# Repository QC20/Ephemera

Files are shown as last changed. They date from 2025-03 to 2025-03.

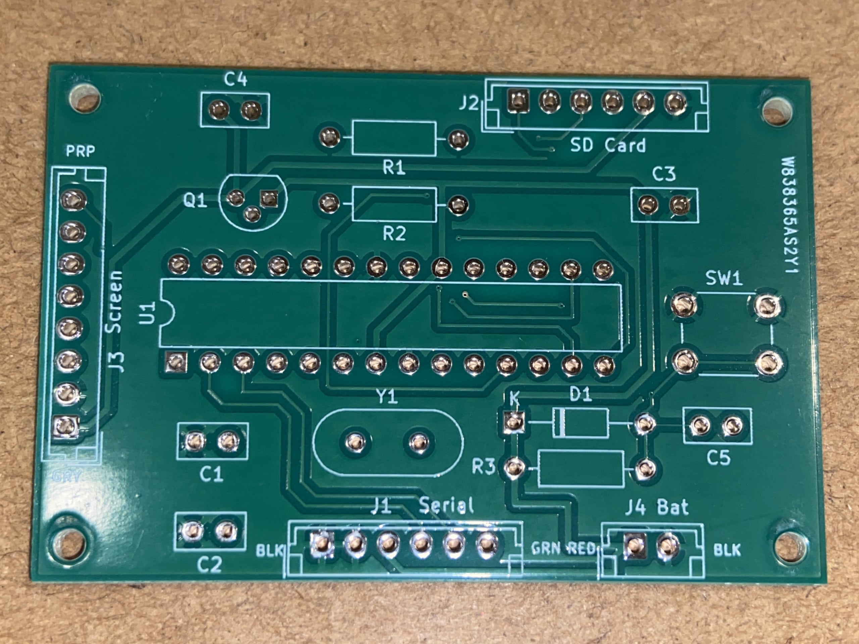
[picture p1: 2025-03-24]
img/pcb-silkscreen-without-components.jpeg

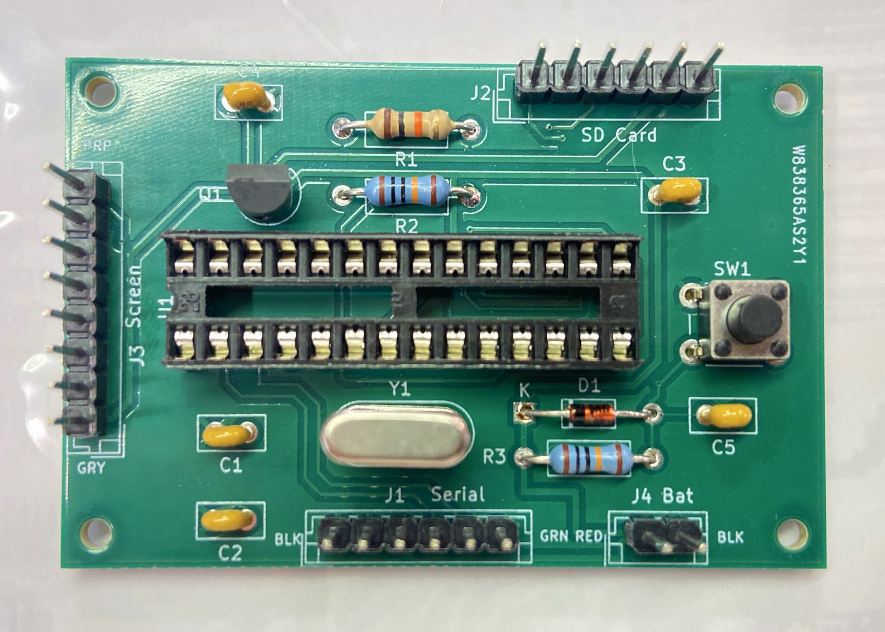
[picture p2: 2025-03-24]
img/pcb-silkscreen-with-components.jpeg

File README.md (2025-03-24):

# Ephemera

This guide offers everything you need to assemble a versatile e-paper picture frame that refreshes its display daily. At its heart is a Waveshare seven-color e-paper display, enhanced with the Floyd-Steinberg Dithering algorithm to give the impression of greater color depth. With the included BMP-Converter, you can easily prepare and customize your own images for display. The frame also supports internet connectivity, allowing you to schedule specific images for special days. Powered by a 1000mAh battery, the setup can run for up to 700 days on a single charge, with convenient recharging available via the ESP32's type-C port.

**Ephemera** is a dynamic e-paper project that brings fresh visual inspiration every day. It curates and displays a new, unique image daily, celebrating the fleeting beauty of each moment. Designed to capture the essence of *ephemera*—the transitory and temporary—this project offers a constantly evolving collection of images, here today and replaced tomorrow.

Whether you're here for daily inspiration, a unique view, or just curious to see what’s new, Ephemera invites you to enjoy each passing frame.

## Features
- **Daily Image Updates:** New content every day to keep things fresh.
- **Minimalist Design:** Clean, distraction-free visuals to let each image stand out.
- **Easy to Extend:** Perfect for those interested in learning about e-paper projects and automation.

---

### The Display 

The Waveshare 7.3" ACeP 7-Color display supports 7 colors (black, white, red, green, blue, orange and yellow).

### Frame Dimensions

The following dimensions are designed to fit the display, so the frame can be any size as long as it accommodates these internal measurements. However, it’s important to ensure there is enough space on the backside for the components. Depending on the battery type you use, the most protruding components will be the crystal and the wires on the PCB, which extend about 10mm. If you can find a  deep frame that allows for this additional space, it would be the ideal solution.

**Dimensions (inches):**  in 5 (L) x 7 in (W)
**Dimensions (mm):** 192 mm (L) x 222 mm (W)

### Components Used in this Project
To bring **Ephemera** to life, you'll need a carefully chosen set of components to ensure low power consumption and seamless operation. Below is a detailed list of the required parts, along with their approximate costs in DKK, to help you build your own dynamic e-paper display.

- **FireBeetle 2 ESP32-E (61.10 DKK):**  
  A microcontroller designed for low power consumption during deep sleep.  
  [Buy here](https://www.dfrobot.com/product-2195.html)

- **Li-Po 503450 1000mAh 3.7V with PH2.0 connector (~17.20 DKK each):**  
  A rechargeable lithium polymer battery for power supply.  
  *(Dimensions: 5mm (H) x 34mm (W) x 50mm (L))*  
  [Buy here](https://yourlink.com)

- **Micro SD Card Module (~2.80 DKK each):**  
  A module for interfacing with micro SD cards.  
  Operates at 4.5V–5.5V DC with a current range of 0.2mA–200mA.  
  Communicates via a standard SPI interface (3.3V or 5V logic level).  
  Compatible with Micro SD cards (up to 2dB) and Micro SDHC cards (up to 32GB).
  Note this version does not take SDXC cards. Maybe orther card modules will. I have not tested.   
  Control pins:  
  - **GND**: Ground  
  - **3V3**: Power supply  
  - **MISO, MOSI, CLK**: SPI bus  
  - **CS**: Chip select signal pin  
  *(Dimensions: 18mm x 18mm)*  
  [Buy here](https://de.aliexpress.com/item/1005005591145849.html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)

- **Waveshare 7.3-inch ACeP 7-Color E-Paper E-Ink Display Module + HAT (~522.80 DKK):**  
  A seven-color e-paper display module with SPI communication, featuring 800×480 resolution.  
  [Buy here](https://www.waveshare.com/7.3inch-e-paper-hat-f.htm)

- **PN2222A Transistor (0.40 DKK each):**  
  A transistor used to cut power to the SD card and e-paper display when in deep sleep mode.  
  [Buy here](https://de.aliexpress.com/item/1005007293537015.html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)

- **Toggle Switch (Optional):**  
  A switch to completely disconnect power from the battery.  
  *(Thread diameter: 5mm)*  
  [Buy here](https://yourlink.com)

- **Printed Case:**  
  A custom 3D-printed case to securely hold all components.

- **Four Heat Inserts and Screws:**  
  M3 screws and heat inserts for assembling the components.  
  [Buy here](https://yourlink.com)

- **Picture Frame:**  
  A standard photo frame compatible with the e-paper display module.  
  [Buy here](https://yourlink.com)

### Total Cost for Essential Components: ~627.50 DKK

---

### Assembly Instructions: Soldering Components to the PCB Board

To begin assembly, carefully solder the components onto the PCB board following the silkscreen markings. The silkscreen provides clear indicators for the placement of each component based on its corresponding number. Refer to the table below for a detailed list of components and their specifications.

### Component List

| **Component Number** | **Part** |
|---|---|
| C1, C2 | 22pF |
| C3, C4, C5 | 100nF |
| D1 | General Purpose Diode |
| J1, J2 | Male Connector 01x06 Pin |
| J3 | Male Connector 01x08 Pin |
| J4 | Male Connector 01x02 Pin |
| Q1 | PMOS - LP0701N3-G |
| R1 | 10K Resistor |
| R2, R3 | 100K Resistor |
| SW1 | Push Button Switch |
| U1 | 28 Pin Connector for ATmega328-P|
| Y1 | 16MHz Crystal |

---

### EEPROM & Image Sequence

As the program's logic maintains the position of the image sequence using EEPROM memory, which persists even when powered off. To force the display to restart from the first image, you'll need to clear the EEPROM using the provided erase program before uploading the main program again.

The included `delete-eeprom.ino` will reset the counter to zero, meaning you will be able to show images starting from 'bmp-001'.

*Capture the moment. Tomorrow brings something new.*

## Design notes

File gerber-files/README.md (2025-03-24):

## Gerber Files and Schematics

The Gerber files and schematics used in this project were sourced from [rob-g2-365](https://github.com/rob-g2-365/waveshare_epaper_picture_frame). This design closely matched the requirements of this project, so instead of designing something similar from scratch, I opted to use and adapt this existing design.

---

## About the PCB Design

The PCB board is built around an **Atmel ATmega328P** microcontroller and can be programmed using the Arduino IDE as an **Arduino Uno**. The circuit is straightforward, with a focus on providing exposed pins for the following connections:
- **External SD Card**  
- **6-Pin Screen Connector**  
- **Battery Connector**  
- **Serial Output Pins** for FTDI connectivity during the initial flashing process  

---

## Flashing the ATmega328P Chip

If you don’t have an FTDI connector, you can use an **Arduino Uno Rev3** to flash the chip. Simply program the chip on the Arduino Uno board, then transfer it back to the PCB for use.

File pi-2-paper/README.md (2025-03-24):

# Raspberry Pi Zero 2 ePaper Display Setup Guide

> **Note**: This is a condensed guide. For complete details, visit the official documentation at [Waveshare's Wiki](https://www.waveshare.com/wiki/7.3inch_e-Paper_HAT_(F)_Manual#Working_With_Raspberry_Pi)

## Hardware Connection
- Connect the ePaper HAT directly to Raspberry Pi's 40PIN header
- Alternative: Use 8PIN cable with following connections:
  ```
  VCC → 3.3V
  GND → GND
  DIN → MOSI (19)
  CLK → SCLK (23)
  CS  → CE0 (24)
  DC  → GPIO 22
  RST → GPIO 11
  BUSY → GPIO 18
  ```

## Software Setup

### 1. Enable SPI
```bash
sudo raspi-config
# Navigate: Interfacing Options → SPI → Yes
sudo reboot
```

### 2. Install Required Libraries
```bash
# Install BCM2835
wget http://www.airspayce.com/mikem/bcm2835/bcm2835-1.71.tar.gz
tar zxvf bcm2835-1.71.tar.gz
cd bcm2835-1.71/
sudo ./configure && sudo make && sudo make check && sudo make install

# Install lg library
wget https://github.com/joan2937/lg/archive/master.zip
unzip master.zip
cd lg-master
make
sudo make install
```

### 3. Download and Compile Demo
```bash
# Get demo code
git clone https://github.com/waveshare/e-Paper.git
cd e-Paper/RaspberryPi_JetsonNano/

# Compile
cd c
sudo make clean
sudo make -j4 EPD=epd7in3f

# Run demo
sudo ./epd
```

## Troubleshooting
- Verify SPI is not occupied: `ls /dev/spi*` should show `/dev/spidev0.1` and `/dev/spidev0.1`
- Check `/boot/config.txt` for `dtparam=spi=on` entry

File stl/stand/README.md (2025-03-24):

## Recommended Printing Settings

Layer Height: 0.15mm
Infill: 10%-15%
Supports: Baseplate

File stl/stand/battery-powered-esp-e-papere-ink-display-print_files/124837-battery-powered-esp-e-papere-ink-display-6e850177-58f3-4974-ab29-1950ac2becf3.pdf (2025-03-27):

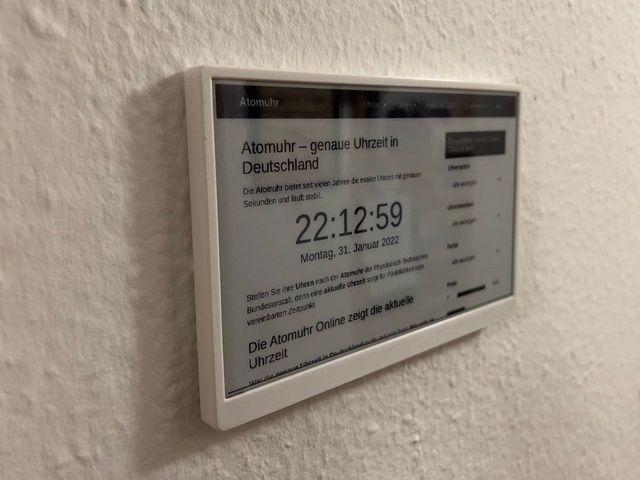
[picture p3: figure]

0.94 hrs

2 pcs

f

0.20 mm

k

0.40 mm

h

PET

16 g

d

Prusa MINI /
MINI+

## Summary

Uses the Waveshare 7.5" ePaper with ESP8266 driver board.

Hobby & Makers (https://printables.com/model?categoryId=48) > Electronics (https://printables.com/model?categoryId=52)

Tags: display | battery | esp8266 | esp | waveshare | eink
epaper | homeautomation | waveshare75inch

To close the two halves, push a piece of filament through the holes on top. The small slot in the top middle is for gripping to a nail.

Desolder the pins on the bottom of the ESP8266 driver board to make it thinner. (Tip to make this easier: lift up and remove the plastic between the pins with a screwdriver first)
Hook up a Li-Ion charger module and battery to Vin and GND. To get battery readout, connect A0 and Vin with a 100k resistor. (Then calibrate the adc readout with a multimeter)
To enable deep sleep, short D0(GPIO16) to RST.

S (https://printables.com/@Sev_198083) Sev (https://printables.com/@Sev_198083)

## Battery powered esp e-paper/e-ink display

VIEW IN BROWSER (https://printables.com/model/124837-battery-powered-esp-e-papere-ink-display)

updated 19. 9. 2023 | published 19. 9. 2023

1.

2.

3.

## Model files

## Print files

The display is a tight fit, to make sure it works the first time, lower the extrusion multiplier or slice at 100.5% size.
The charger module is held in place with strong double sided tape (eg. Tesa 4965)

The driver board has NO PROTECTION DIODE between Vin and Vusb!!! Always disconnect the battery before plugging in usb on the driver board!

It's using 24mA when idle, ~70mA when refreshing and 1.4mA when in deepsleep. With hourly refresh I get about two months of runtime.

This is what I used:

2x https://www.berrybase.de/strom/batterien-akkus/industrieakkus/lp-785060-lithium-polymer/lipo-akku-3-7v-2500mah-mit-2-pin-jststecker (https://www.berrybase.de/strom/batterien-akkus/industrieakkus/lp-785060-lithium-polymer/lipo-akku-3-7v-2500mah-mit-2-pin-jst-stecker)
https://www.berrybase.de/strom/batterien-akkus/ladegeraete/ladeplatine-f-252-r-3-7v-liion/lipo-akkus-mit-ausgang-usb-type-cbuchse-l-246-tpads-1000ma (https://www.berrybase.de/strom/batterien-akkus/ladegeraete/ladeplatine-f-252-r-3-7v-liion/lipo-akkus-mit-ausgang-usb-type-c-buchse-l-246-tpads-1000ma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)
https://www.berrybase.de/sensoren-module/displays/epaper-displays/7.5-800-215-480-epaper-display-hat-f-252-r-raspberry-pi-v2 (https://www.berrybase.de/sensoren-module/displays/epaper-displays/7.5-800-215-480-epaper-display-hat-f-252-r-raspberry-pi-v2) https://www.welectron.com/Waveshare-14138-e-Paper-ESP8266-Driver-Board_1 (https://www.welectron.com/Waveshare-14138-e-Paper-ESP8266-Driver-Board_1)
h PET | k 0.40 mm | f 0.20 mm | 0.94 hrs | 16 g | d Prusa MINI / MINI+

4.

5.

•

•

•

•

epapercase-front.stl

epapercase-inlay.stl

epapercase-front_02mm_petg_mini_57m.gcode

h PET | k 0.40 mm | f 0.20 mm | 1.70 hrs | 30 g | d Prusa MINI / MINI+

## License

This work is licensed under a
Creative Commons (4.0 International License)

Attribution—Noncommercial—Share Alike (http://creativecommons.org/licenses/by-nc-sa/4.0/)

✖ | Sharing without ATTRIBUTION
✔ | Remix Culture allowed
✖ | Commercial Use
✖ | Free Cultural Works
✖ | Meets Open Definition

epapercase-inlay_02mm_petg_mini_1h42m.gcode

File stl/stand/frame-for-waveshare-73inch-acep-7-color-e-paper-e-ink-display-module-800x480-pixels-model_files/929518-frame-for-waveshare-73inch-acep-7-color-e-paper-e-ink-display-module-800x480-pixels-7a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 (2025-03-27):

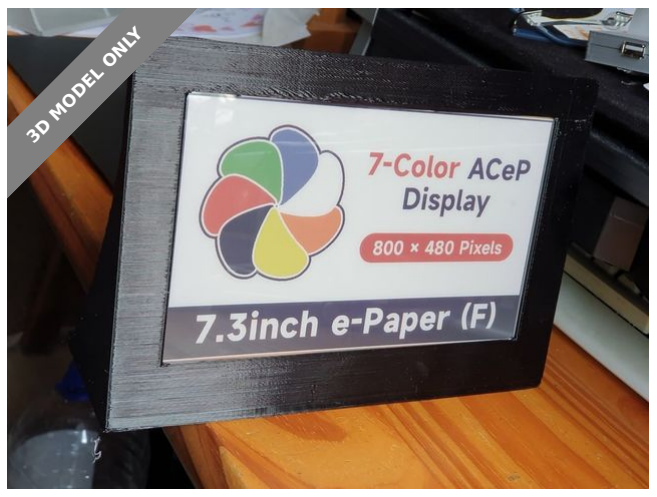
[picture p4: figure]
3D MODEL ONLY

## Summary

Attractive, durable frame for a very delicate panel

Hobby & Makers (https://printables.com/model?categoryId=48) > Other Ideas (https://printables.com/model?categoryId=82)

Tags: | thingiverse | waveshare | waveshare7inch | eink | epaper

I recently saw mention of an affordable seven colour e-paper display on HackerNews and I wanted to try one out as I have a need for a dashboard showing historical sensor readings, and each line would have its own colour. I decided on the 7.3 inch model from Waveshare (https://www.waveshare.com/7.3inch-e-paper-hat-f.htm) as being about as much as I'd be happy to punt. When it arrived, it worked well but was very thin and not at all durable if left loose, so I needed some sort of durable holder.

I was surprised to discover none on any of the 3d printing sites had a frame for this specific size of display with its ribbon at the bottom, so I decided to make my first ever 100% me alone 3d design which is this!

n (https://printables.com/@ned14_2204861) ned14 (https://printables.com/@ned14_2204861)

## Frame for Waveshare 7.3inch ACeP 7-Color E-Paper E-Ink Display Module, 800×480 Pixels

VIEW IN BROWSER (https://printables.com/model/929518-frame-for-waveshare-73inch-acep-7-color-e-paper-e)

updated 1. 7. 2024 | published 1. 7. 2024

Undoubtedly somebody more experienced could do better than this - the rear supports do not have a smooth curve, and some of the seams are slightly prominent in places. I think these mostly from my settings in PrusaSlicer than the STL however. I attach the MeshMixer files so you can fiddle with the design yourself.

The photos are of a black shiny PETG print which I thought would look nice, the "piano shine" you get off PETG I've never seen off any PLA I've tried the shiniest of which has a duller shine. I should have used a hotter temperature, I used 220 C and undoubtedly 230 C would have been better. Still, it's "good enough" for my purposes and it'll work just fine in PLA too, an earlier prototype was in PLA and it came out great.

As you'll see in the photos, I had an ulterior motive of fitting in a
Waveshare PoE hat for the Raspberry Pi Zero (https://www.waveshare.com/poe-eth-usb-hub-hat.htm) in its case. The space is exactly right to hold one of those in place, and it provides extra ballast to keep the frame in place. Even if you don't fit your device into the frame, I made the base 5mm thick to provide a bit of weight to make the frame stable.

In between the two middle supports there are pins to mount the cable connector. They are also spaced exactly apart to hold the cable connector horizontally. On my PLA print the pins came in a touch high, the PETG print the pins came in a touch low. Can't win I guess.

Something I did consider but haven't tried is turning on "fuzzy skin" in the slicer. I think that could produce a very nice looking frame indeed.
Print Settings

Printer Brand: Anycubic

Printer: Kobra Go

Rafts: No

Supports: Yes

Resolution: 0.2mm

Infill: 20% Gyroid

Filament: YOYI PETG Black

Notes:

For the PETG I used, min nozzle 230 C, bed 100 C. The PLA prototype was 190 C nozzle and bed 60 C.

## Model files

## Other files

You will likely need supports for the top part of the outer frame, otherwise it sags (you can see it sagged a bit in my photo). It's not end of the world if it does sag slightly, a sharp knife can fix it.
Post-Printing

Cleanup

A rub down with a rough cloth gets rid of the PETG "hair". A few surface imperfections can be removed with a sharp knife. My earlier prototype was printed in PLA and apart from where the seams knit together producing a mild protrusion, it needed almost no cleanup after apart from removing the very few supports needed.
How I Designed This

Meshmixer

My first ever 100% me alone 3D print design! Done in Meshmixer and sliced in PrusaSlicer.

Category: 3D Printing

Find source .stl files on Thingiverse.com (https://www.thingiverse.com/thing:6677838)

frame2.stl

framemix.zip

## License

This work is licensed under a
Creative Commons (4.0 International License)

Attribution-ShareAlike (http://creativecommons.org/licenses/by-sa/4.0/)

✖ | Sharing without ATTRIBUTION
✔ | Remix Culture allowed
✔ | Commercial Use
✔ | Free Cultural Works
✔ | Meets Open Definition

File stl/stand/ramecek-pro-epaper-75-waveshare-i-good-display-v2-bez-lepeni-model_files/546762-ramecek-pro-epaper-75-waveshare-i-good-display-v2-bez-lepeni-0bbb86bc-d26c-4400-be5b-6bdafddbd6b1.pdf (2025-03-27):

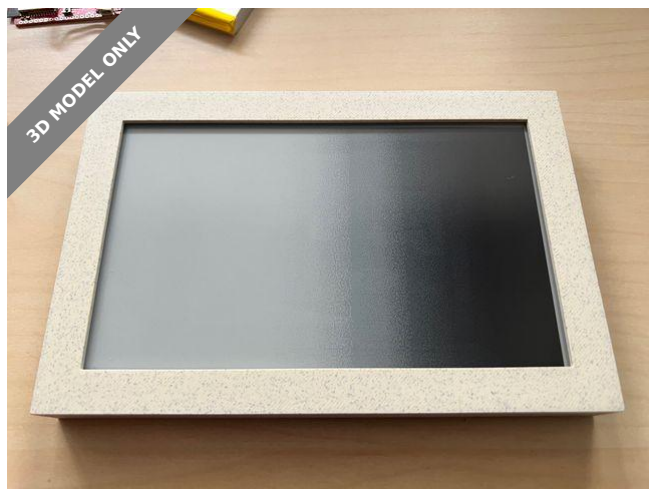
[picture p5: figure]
3D MODEL ONLY

Summary

Rámeček pro ePapery 7.5".

Art & Design (https://printables.com/model?categoryId=13) > Wall-mounted (https://printables.com/model?categoryId=15)

Tags: frame | eink | epaper | ramecek

Do rámečku dostanete ePaper (e-Ink) od Waveshare i Good display s úhlopříčkou 7.5" (170.2x111.2x1.25). Tištěno bez podpěr, 0.15 mm na vrstvu (QUALITY).

Záda k přední části přišroubujte šrouby M2.2x5 (otvory jsou M2), stejně tak vývojovou desku a případné čidlo teploty a vlhkosti.

Pro LiPol baterii je určený chlívek s tím, že případný prostor můžete něčím vycpat, aby nebyla příliš navolno. Pro zavěšení na zeď jsou určené otvory 8 mm.

Záda můžete vytisknout v libovolné barvě (nebudou vidět) a hodí se podpěry (viz obrázek ze sliceru). Záda pro aktuální LáskaKit ESPInk

desku 2.5 jsou “ePaper⁻7.5-v3-back-no⁻battery-compartment.

3mf”!

MultiTricker (https://printables.com/@MultiTricker)

Rámeček pro

ePaper 7.5"

Waveshare i Good

Display - v2 bez

lepení

VIEW IN BROWSER (https://printables.com/model/546762-ramecek-pro-epaper-75-waveshare-i-good-display-v2-)

updated 13. 11. 2023 | published 13. 11. 2023

### Model files

Vývojová deska: https://www.laskakit.cz/laskakit-espink-esp32-e-paperpcb-antenna/?variantId=12416 (https://www.laskakit.cz/laskakit-espink-esp32-e-paper-pcb-antenna/?variantId=12416)
Šroubky: https://www.laskakit.cz/sroub-do-termoplastu-s-cockovou-hlavoua-krizovou-drazkou-2-2x5-bn-82428-ocel/ (https://www.laskakit.cz/sroub-do-termoplastu-s-cockovou-hlavou-a-krizovou-drazkou-2-2x5-bn-82428-ocel/)
ePaper - rozměrově by měly všechny 7.5" sedět (170.2x111.2x1.25), ať už jde o BW, Grayscale, 3C nebo 7C.
Baterie - vejde se většina (i když je v LiPol velký výběr), případně můžete využít volný prostor a přilepit ji oboustrankou.
Čidlo teploty a vlhkosti - https://www.laskakit.cz/laskakit-sht40-senzorteploty-a-vlhkosti-vzduchu/ (https://www.laskakit.cz/laskakit-sht40-senzor-teploty-a-vlhkosti-vzduchu/)

2023-10-12 - zadní strana V3 pro novou ESPInk desku od LáskaKitu. 2023-11-13 - zadní strana V4 - přidán montážní otvor pro desku ES3Ink od @Dronecz.

- Moderní přední strana se zkosením směrem k displeji - elegantní a opticky rámeček zužuje.
- Aktualizovaná zadní strana pro novou ESPInk desku desku v2.5 a ES3ink.
- Původní přední strana rámečku bez zkosení.
- Zadní strana - s prostorem pro baterku, ve kterém je potřeba konkrétní model "dovystlat".
- Zadní strana - bez prostoru pro baterku, takže tu lepit na sucháč/oboustrankou.

epaper⁻75-v2-front⁻chamfer.3mf

epaper⁻75-v4-back-no⁻battery-compartment.3mf

epaper⁻75-v2-front.3mf

epaper⁻75-v2-back.3mf

epaper⁻75-v2-back-no⁻battery-compartment.3mf

License

This work is licensed under a
Creative Commons (4.0 International License)

Attribution (http://creativecommons.org/licenses/by/4.0/)

✖ | Sharing without ATTRIBUTION
✔ | Remix Culture allowed
✔ | Commercial Use
✔ | Free Cultural Works
✔ | Meets Open Definition

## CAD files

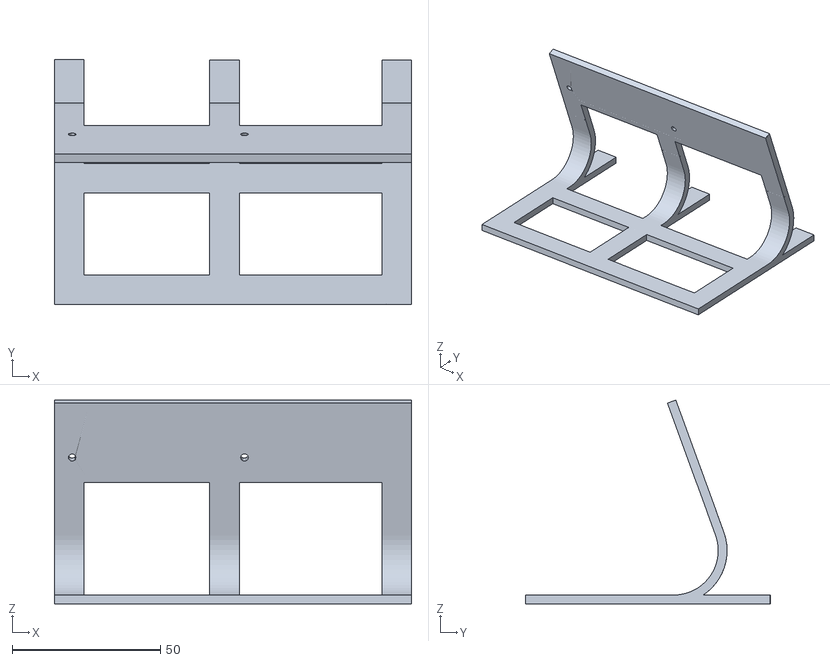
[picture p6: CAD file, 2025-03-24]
stl/stand/PiInk_stand_7.3_Inch.stl
120.4 x 82.8 x 68.7

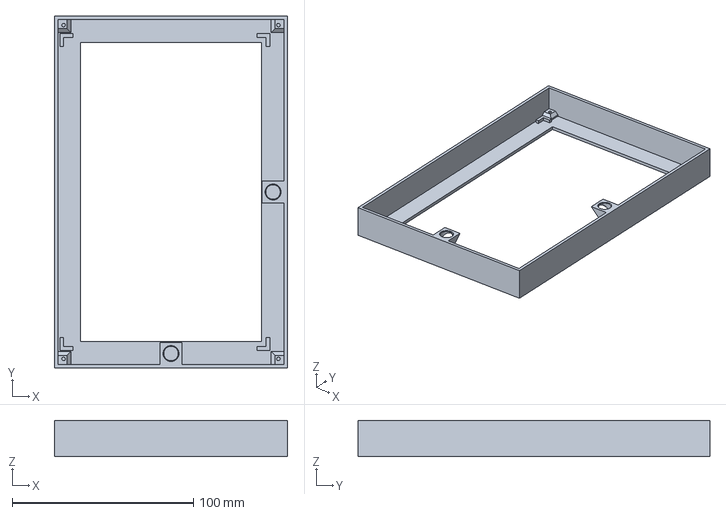
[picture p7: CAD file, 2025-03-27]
stl/stand/ramecek-pro-epaper-75-waveshare-i-good-display-v2-bez-lepeni-model_files/ePaper-7.5-v2-front.3mf
128.7 x 194.4 x 20.0 mm

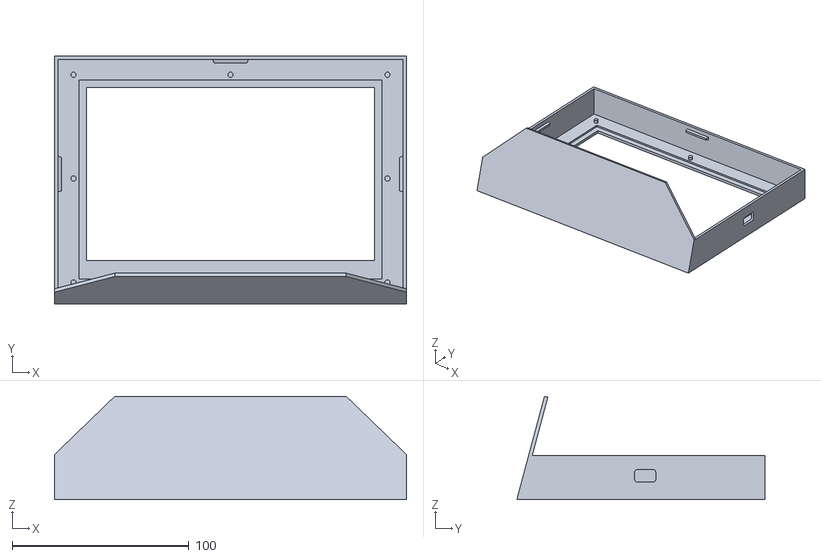
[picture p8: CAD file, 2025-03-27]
stl/stand/waveshare-75-inch-epaper-case-for-dfrobot-firebeetle-model_files/outside_firebeetle_15dgrrotated.stl
199.2 x 140.6 x 58.5

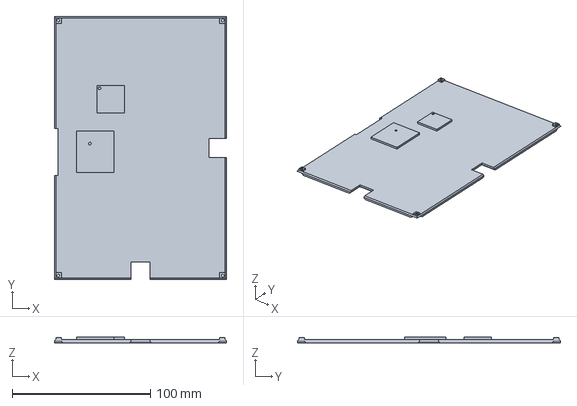
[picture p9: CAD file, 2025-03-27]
stl/stand/ramecek-pro-epaper-75-waveshare-i-good-display-v2-bez-lepeni-model_files/ePaper-7.5-v2-back-no-battery-compartment.3mf
124.3 x 190.0 x 4.20 mm

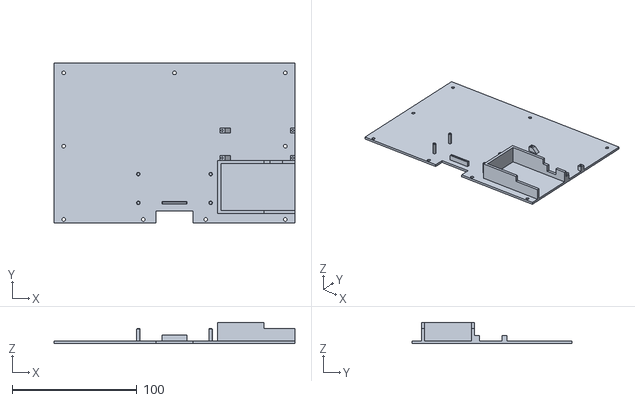
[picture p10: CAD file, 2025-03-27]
stl/stand/waveshare-75-inch-epaper-case-for-dfrobot-firebeetle-model_files/inside_firebeetle.stl
193.2 x 127.9 x 17.0

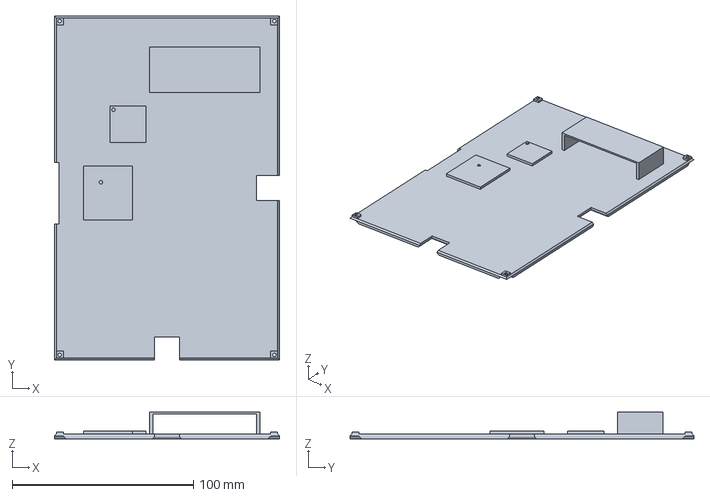
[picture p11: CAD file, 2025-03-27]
stl/stand/ramecek-pro-epaper-75-waveshare-i-good-display-v2-bez-lepeni-model_files/ePaper-7.5-v2-back.3mf
124.3 x 190.0 x 14.7 mm

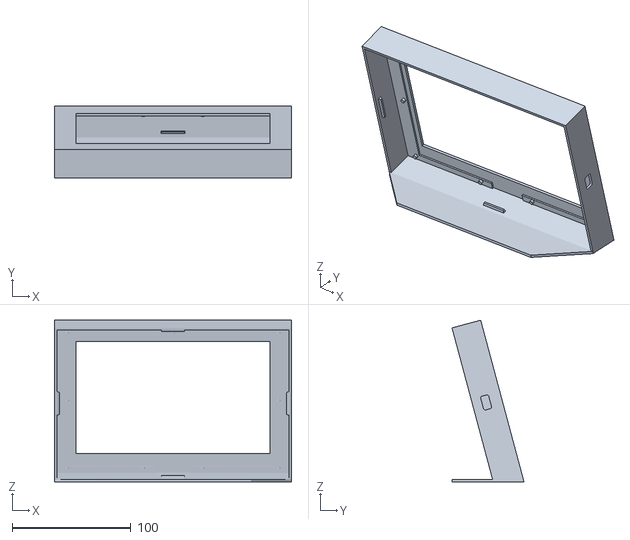
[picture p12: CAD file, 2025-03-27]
stl/stand/waveshare-75-inch-epaper-case-for-dfrobot-firebeetle-model_files/outside_firebeetle_15dgr.stl
199.2 x 60.5 x 135.8

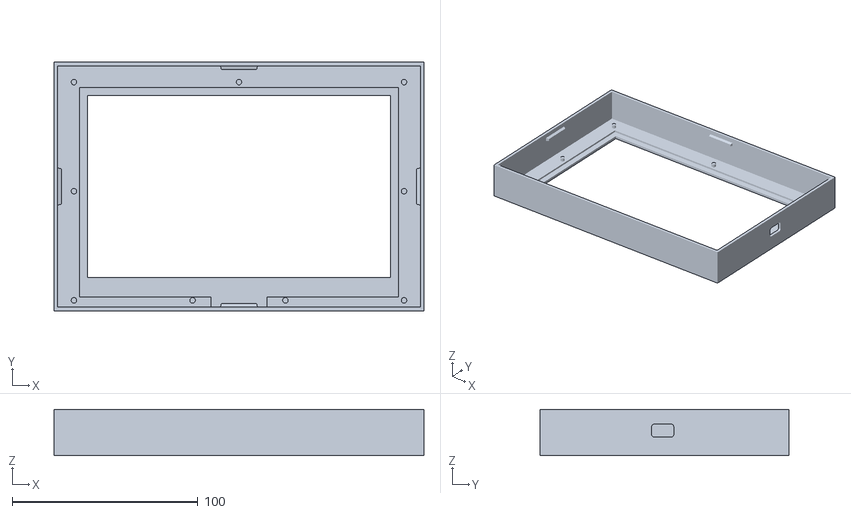
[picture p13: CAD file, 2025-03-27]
stl/stand/waveshare-75-inch-epaper-case-for-dfrobot-firebeetle-model_files/outside_firebeetle.stl
199.2 x 133.9 x 25.0

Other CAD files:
stl/stand/ramecek-pro-epaper-75-waveshare-i-good-display-v2-bez-lepeni-model_files/ePaper-7.5-v2-front-chamfer.3mf
stl/stand/ramecek-pro-epaper-75-waveshare-i-good-display-v2-bez-lepeni-model_files/epaper-75-v4-back-no-battery-compartment.3mf

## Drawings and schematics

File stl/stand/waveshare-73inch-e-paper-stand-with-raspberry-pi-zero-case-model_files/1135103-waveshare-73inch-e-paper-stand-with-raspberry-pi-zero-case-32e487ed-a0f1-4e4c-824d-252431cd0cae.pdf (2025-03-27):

## WaveShare 7.3inch e-Paper stand with

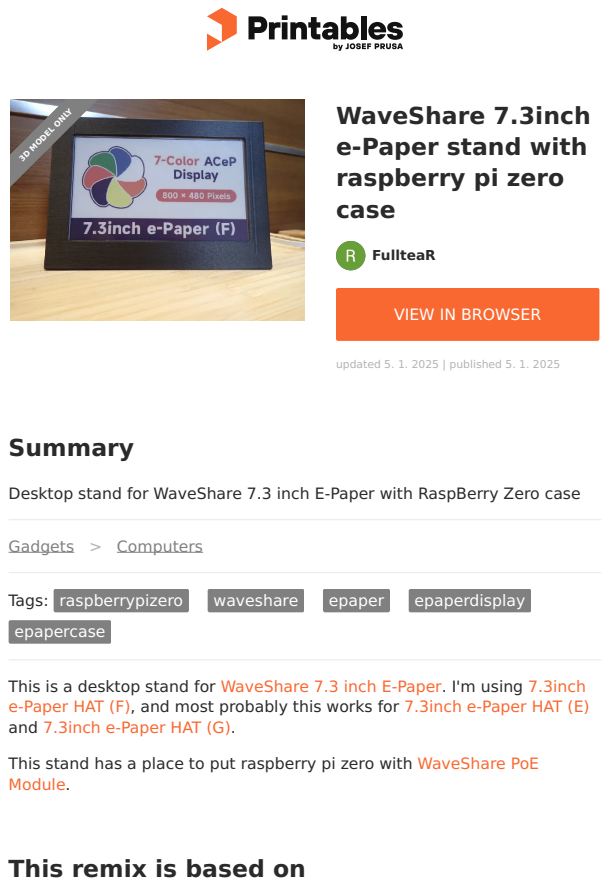
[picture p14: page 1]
Summary; Gadgets > Computers; Tags:; raspberrypizero; waveshare; epaper; epaperdisplay; epapercase; FullteaR; updated 5. 1. 2025 | published 5. 1. 2025; 3D MODEL ONLY

raspberry pi zero
case

VIEW IN BROWSER (https://printables.com/model/1135103-waveshare-73inch-e-paper-stand-with-raspberry-pi-z)

Desktop stand for WaveShare 7.3 inch E-Paper with RaspBerry Zero case

This is a desktop stand for WaveShare 7.3 inch E-Paper. (https://www.waveshare.com/7.3inch-e-paper-hat-f.htm) I'm using 7.3inch
e-Paper HAT (F), (https://www.waveshare.com/7.3inch-e-paper-hat-f.htm) and most probably this works for 7.3inch e-Paper HAT (E) (https://www.waveshare.com/7.3inch-e-paper-hat-e.htm)
and 7.3inch e-Paper HAT (G). (https://www.waveshare.com/7.3inch-e-paper-hat-g.htm)

This stand has a place to put raspberry pi zero with WaveShare PoE
Module. (https://www.waveshare.com/poe-eth-usb-hub-hat.htm)

This remix is based on

## Model files

Frame for Waveshare 7.3inch ACeP 7-Color E-Paper E-Ink Display Module, 800×480 Pixels (https://printables.com/model/929518-frame-for-waveshare-73inch-acep-7-color-e-paper-e)
by ned14 (https://printables.com/@ned14_2204861)

## License

This work is licensed under a
Creative Commons (4.0 International License)

Attribution-ShareAlike (http://creativecommons.org/licenses/by-sa/4.0/)

✖ | Sharing without ATTRIBUTION
✔ | Remix Culture allowed
✔ | Commercial Use
✔ | Free Cultural Works
✔ | Meets Open Definition

waveshare-frame-with-case.stl

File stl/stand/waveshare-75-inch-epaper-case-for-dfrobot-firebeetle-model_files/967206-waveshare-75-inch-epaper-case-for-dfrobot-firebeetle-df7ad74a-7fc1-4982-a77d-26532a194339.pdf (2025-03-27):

## Waveshare 7.5 inch ePaper case for

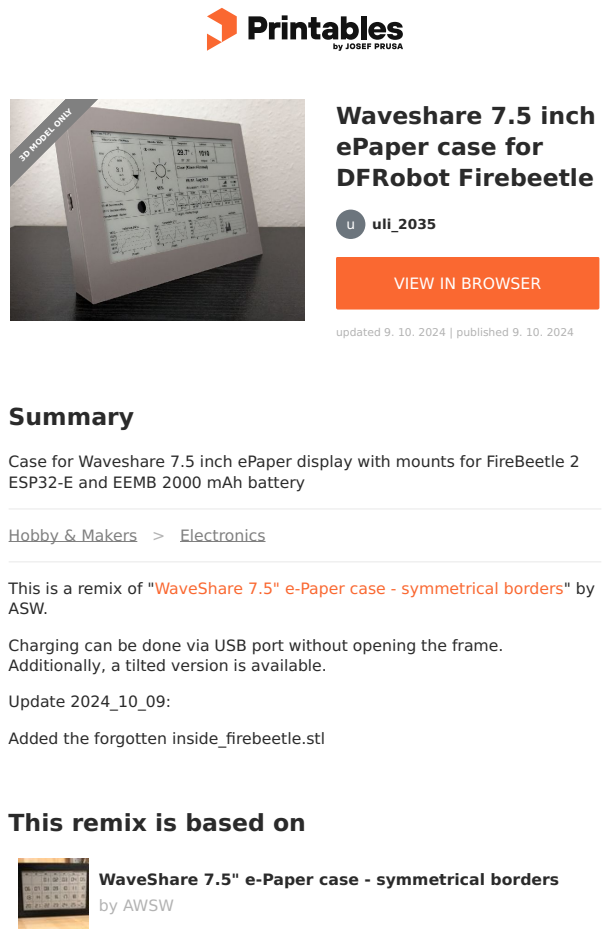
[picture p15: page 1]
Summary; Update 2024_10_09:; uli_2035; DFRobot Firebeetle; updated 9. 10. 2024 | published 9. 10. 2024; 3D MODEL ONLY

VIEW IN BROWSER (https://printables.com/model/967206-waveshare-75-inch-epaper-case-for-dfrobot-firebeet)

Case for Waveshare 7.5 inch ePaper display with mounts for FireBeetle 2
ESP32-E and EEMB 2000 mAh battery

Hobby & Makers (https://printables.com/model?categoryId=48) > Electronics (https://printables.com/model?categoryId=52)

This is a remix of "WaveShare 7.5" e-Paper case - symmetrical borders" (https://www.printables.com/model/219811-waveshare-75-e-paper-case-symmetrical-borders) by
ASW.

Charging can be done via USB port without opening the frame.
Additionally, a tilted version is available.

Added the forgotten inside_firebeetle.stl

This remix is based on

WaveShare 7.5" e-Paper case - symmetrical borders (https://printables.com/model/219811-waveshare-75-e-paper-case-symmetrical-borders)
by AWSW (https://printables.com/@AWSW)

## Model files

## License

This work is licensed under a
Creative Commons (4.0 International License)

Attribution-NonCommercial (http://creativecommons.org/licenses/by-nc/4.0/)

✖ | Sharing without ATTRIBUTION
✔ | Remix Culture allowed
✖ | Commercial Use
✖ | Free Cultural Works
✖ | Meets Open Definition

outside_firebeetle.stl

outside_firebeetle_15dgr.stl

outside_firebeetle_15dgrrotated.stl

inside_firebeetle.stl

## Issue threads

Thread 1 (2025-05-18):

Digital Frame Experience

nizh0001, 2025-05-18:
Hi @QC20,

We’re a small student team working on a free mobile app designed to help users easily crop, organize, add metadata, and upload photos to digital picture frames.

Your project caught our attention — as someone building a digital frame, your feedback would be incredibly valuable!

We’ve created a short (5–10 minute) survey to better understand user needs and experiences. Your input would go a long way in helping us build something truly useful for the community:

👉 https://forms.office.com/Pages/ResponsePage.aspx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

Thanks so much! If this isn’t the right place to post, just let us know — we’ll be happy to remove it.

— TechnoLab Student Team

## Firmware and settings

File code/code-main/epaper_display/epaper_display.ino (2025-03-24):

/******************************************************************************
File: epaper_display.ini
******************************************************************************
MIT License

Copyright (c) 2023 Robert L Gorsegner II

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
THE SOFTWARE IS PROVIDED "AS IS", WITHOUT WARRANTY OF ANY KIND, EXPRESS OR
IMPLIED, INCLUDING BUT NOT LIMITED TO THE WARRANTIES OF MERCHANTABILITY,
FITNESS FOR A PARTICULAR PURPOSE AND NONINFRINGEMENT. IN NO EVENT SHALL THE
AUTHORS OR COPYRIGHT HOLDERS BE LIABLE FOR ANY CLAIM, DAMAGES OR OTHER
LIABILITY, WHETHER IN AN ACTION OF CONTRACT, TORT OR OTHERWISE, ARISING FROM,
OUT OF OR IN CONNECTION WITH THE SOFTWARE OR THE USE OR OTHER DEALINGS IN THE
SOFTWARE.
******************************************************************************/
#include <Arduino.h>
#include <SD.h>
#include <LowPower.h>
#include <SPI.h>
#include <EEPROM.h>
#include <avr/pgmspace.h>
#include "epd7in3f.h"
#include "epdif.h"
#include "read_bmp.h"
#include "eeprom_data.h"
#include "debug.h"
#include "picture_index.h"


// Definitions
#define PIN_POWER_SELECT    5
#define PIN_SD_CHIP_SELECT  6
#define PIN_MOSI            11
#define PIN_SCLK            13

#define SECONDS_IN_A_DAY  86400
#define SECONDS_TO_DISPLAY 135
#define NUMBER_OF_SLEEP_LOOPS   ((SECONDS_IN_A_DAY - SECONDS_TO_DISPLAY)/8)

// Function declarations.
int get_next_file_handle(SDFile &sdFile);
inline void beginSpiTransaction() __attribute__((always_inline));
inline void endSpiTransaction() __attribute__((always_inline));
void sendQuarterRow(Epd *pEpd, char *buffer);

// Global variables
long sleep_loops = 0;

/******************************************************************************
function : 
      Setup
******************************************************************************/
void setup() {
  // put your setup code here, to run once:
  // Set up serial port baud rate for debug
  Debug::serialBegin(9600);

  Debug::printEepromErrorInfo();

  int pictureIndex = EepromData::readPictureIndex();

  #ifdef SERIAL_DEBUG
  Debug::printProgMem(PSTR("Starting off from picture index "));
  Serial.print(pictureIndex, DEC);
  Serial.print("\r\n");
  #endif // SERIAL_DEBUG

  PictureIndex::setPictureIndex(pictureIndex);
}

/****************************************************************************** 
 * Function: Main loop 
 * 
 * Description: 
 * 1. Powers up necessary components. 
 * 2. Updates the display with a new image. 
 * 3. Powers down components to conserve energy. 
 * 4. Manages the device's deep sleep mode. 
 ******************************************************************************/

void loop() {

  powerUpPeripherals();
  updateDisplayWithNewPicture();
  powerDownPeripherals();

  while(sleep_loops < NUMBER_OF_SLEEP_LOOPS) {
    Debug::printProgMem(PSTR("Sleeping\r\n"));

    Debug::serialFlush();
    LowPower.powerDown(SLEEP_8S, ADC_OFF, BOD_OFF); 
    sleep_loops++;

    Debug::printProgMem(PSTR("Waking\r\n"));
  }
  sleep_loops = 0;
}

/******************************************************************************
  Update the display with a new picture
******************************************************************************/
void updateDisplayWithNewPicture() {
  bool bmpFileInit = false;
  Epd epd;
  SDFile bmpFile;

  Debug::printProgMem(PSTR("epd.Init()\r\n"));
  if (epd.Init() != SUCCESS) {
    Debug::printProgMem(PSTR("e-Paper init failed.\r\n"));
    Debug::error(ERRORCODE_EPAPER_INIT_FAILED);
    return;
  }

  // Clear the display.
  Debug::printProgMem(PSTR("e-Paper Clear\r\n"));
  beginSpiTransaction();
  epd.Clear(EPD_7IN3F_WHITE);
  endSpiTransaction();

  SD.begin(SPI_QUARTER_SPEED, PIN_SD_CHIP_SELECT);
  // getNextFileHandle has the error handling code in it.
  if( getNextFileHandle(bmpFile) == FAILURE) {
    goto cleanup;
  }
  bmpFileInit = true;

  Debug::printProgMem(PSTR("Display Image\r\n"));
  displayImage(&epd, bmpFile);
  // epd.EPD_7IN3F_Show7Block();

  // Delay 3 seconds while the image shows on the screen.
  delay(3000);

cleanup:  
  Debug::printProgMem(PSTR("EPaper Sleep...\r\n"));
  beginSpiTransaction();
  epd.Sleep();
  endSpiTransaction();

  // Close the file handle.
  if(bmpFileInit) {
    bmpFile.close();
  }

  // Close the SD Card.
  SD.end();
  PictureIndex::updateInUsePictureIndex();
}

/******************************************************************************
  Power up the SDCARD and E-Hat
******************************************************************************/
void powerUpPeripherals() {
  Debug::printProgMem(PSTR("powerUpPeripherals\r\n"));

  // Set the SDCARD CS, SCLK and MOSI pins high so the SD CARD doesn't start 
  // reading the SPI bus when powered up. Flush every debug serial port 
  // transaction so that if there is a problem the last message is logged.
  Debug::printProgMem(PSTR("pinMode(PIN_SD_CHIP_SELECT, OUTPUT)\r\n"));
  Serial.flush();
  pinMode(PIN_SD_CHIP_SELECT, OUTPUT);

  Debug::printProgMem(PSTR("digitalWrite(PIN_SD_CHIP_SELECT, HIGH)\r\n"));
  Serial.flush();
  digitalWrite(PIN_SD_CHIP_SELECT, HIGH);

  Debug::printProgMem(PSTR("pinMode(PIN_SCLK, OUTPUT)\r\n"));
  Serial.flush();
  pinMode(PIN_SCLK, OUTPUT);

  Debug::printProgMem(PSTR("digitalWrite(PIN_SCLK, HIGH)\r\n"));
  Serial.flush();
  digitalWrite(PIN_SCLK, HIGH);
  
  Debug::printProgMem(PSTR("pinMode(PIN_MOSI, OUTPUT)\r\n"));
  Serial.flush();
  pinMode(PIN_MOSI, OUTPUT);

  Debug::printProgMem(PSTR("digitalWrite(PIN_MOSI, HIGH)\r\n"));
  Serial.flush();
  digitalWrite(PIN_MOSI, HIGH);


  // Turn on the peripheral power by setting power select low.
  Debug::printProgMem(PSTR("pinMode(PIN_POWER_SELECT, OUTPUT)\r\n"));
  Serial.flush();
  pinMode(PIN_POWER_SELECT, OUTPUT);
  digitalWrite(PIN_POWER_SELECT, LOW);

  // Allow a small delay for the peripherals to get power.
  Debug::printProgMem(PSTR("delay(2)\r\n"));
  delay(2);

  Debug::printProgMem(PSTR("-powerUpPeripherals\r\n"));
}

/******************************************************************************
  Power down the SDCARD and E-Hat
******************************************************************************/
void powerDownPeripherals() {
  Debug::printProgMem(PSTR("powerDownPeripherals\r\n"));
  // Turn off the peripheral power by setting the power select GPIO high.  
  // The power will remain off while sleeping.
  digitalWrite(PIN_POWER_SELECT, HIGH);

  
  // If SCLK, MOSI or the CS lines are high, the SD Card board will draw power on some
  // SD Card boards.  This can be prevented by setting these lines as inputs.
  pinMode(PIN_SCLK, INPUT);
  pinMode(PIN_MOSI, INPUT);
  pinMode(PIN_SD_CHIP_SELECT, INPUT);
}

/******************************************************************************
  Get next file.  Remember to close the file handle after use.

  @param[out] sdFile
         Pointer to the display object.

  @retval SUCCESS
  @retval FAILURE
******************************************************************************/
int getNextFileHandle(SDFile &sdFile) {
  char filename[MAX_8_3_FILENAME_SIZE];

  // Get the next filename.
  Debug::printProgMem(PSTR("Get the next filename\r\n"));
  PictureIndex::getBmpFilename(filename);

  Debug::printProgMem(PSTR("Opening file "));
  Debug::print(filename);
  Debug::print("\r\n");
  sdFile = SD.open(filename, FILE_READ);
  if(sdFile) {
    Debug::printProgMem(PSTR("File opened.\r\n"));
    PictureIndex::incrementPictureIndex();
    EepromData::savePictureIndex();
    return SUCCESS;
  }

  if(PictureIndex::getPictureIndex()==0) {
    // Do not log the first picture to the eeprom because this is easy to reproduce.
    Debug::printProgMem(PSTR("Failed to open file pic_000.bmp.\r\n"));
    return FAILURE;
  } 

  Debug::printProgMem(PSTR("Failed to open file.\r\n"));
  sdFile.close();

  // Sent the picture index to the original.
  PictureIndex::clearPictureIndex();
  PictureIndex::updateInUsePictureIndex();
  PictureIndex::getBmpFilename(filename);

  Debug::printProgMem(PSTR("Opening file "));
  Debug::print(filename);
  Debug::printProgMem(PSTR("\r\n"));
  sdFile = SD.open(filename, FILE_READ);
  if(sdFile) {
    Debug::printProgMem(PSTR("File opened."));
    PictureIndex::incrementPictureIndex();
    EepromData::savePictureIndex();
    return SUCCESS;
  }

  Debug::printProgMem(PSTR("Failed to open any bmp file.\r\n"));
  return FAILURE;
}

/******************************************************************************
  Displays the image.

  @param pEpd
         Pointer to the display object.
  @param filename
         Filename of the bitmap.

  @retval SUCCESS
  @retval FAILURE
******************************************************************************/
int displayImage(Epd * pEpd, SDFile & bmpFile) {
  int ret = SUCCESS;
  // Send the command to start writing the data buffer.
  Debug::printProgMem(PSTR("pEpd->SendCommand(0x10)\r\n"));
  beginSpiTransaction();
  pEpd->SendCommand(0x10);
  endSpiTransaction();

  // Create the ReadBMP class
  ReadBMP readbmp(&bmpFile);

  if (readbmp.parseHeader() != SUCCESS) {
    // Close the data file
    ret = FAILURE;
    goto display_image_cleanup;
  }

  if(readbmp.width() != EPD_WIDTH || readbmp.height() != EPD_HEIGHT ) {
    Debug::printProgMem(("Invalid image size.\r\n"));
    Debug::error(ERRORCODE_BMP_INVALID_IMAGE_SIZE);
    ret = FAILURE;
    goto display_image_cleanup;
  }

  {
    char quarterLineBuffer[EPD_WIDTH/4];
    for(int row = 0; row < EPD_HEIGHT; row++) {
      for(int quarter = 0; quarter < 4 ; quarter++) {
        // Read in one half row of data. Callee handles error message.
        if(readbmp.readQuarterLine(quarterLineBuffer) == FAILURE) {
          ret = FAILURE;
          goto display_image_cleanup;
        }

        beginSpiTransaction();
        // Write out one half row to the screen.
        sendQuarterRow(pEpd, quarterLineBuffer);
        endSpiTransaction();
      }
    }
  }

  Debug::printProgMem(PSTR("pEpd->TurnOnDisplay()\r\n"));
  beginSpiTransaction();
  ret = pEpd->TurnOnDisplay();
  if( ret== FAILURE) {
    Debug::printProgMem(PSTR("TurnOnDisplay Failed\r\n."));
    Debug::error(ERRORCODE_EPAPER_FAILED_TURN_ON_DISPLAY);
  }

  endSpiTransaction();

display_image_cleanup:
  // Close the data file
  bmpFile.close();

  // Show the image.
  return ret;
}

/******************************************************************************
  Begin a spi transaction for the e-paper screen
******************************************************************************/
void beginSpiTransaction() {
  SPI.beginTransaction(SPISettings(EPD_SPI_SPEED, MSBFIRST, SPI_MODE0));
}

/******************************************************************************
  End a spi transaction for the e-paper screen
******************************************************************************/
void endSpiTransaction() {
  SPI.endTransaction();
}

/******************************************************************************
  Send a half row.  A full row takes up to much memory on the arduino.

  @param buffer A buffer for the half row.

******************************************************************************/
void printHalfRow(char *buffer) {
  #ifdef SERIAL_DEBUG
  for(int col = 0; col< EPD_WIDTH /4 ; col++ ) {
    Serial.print(buffer[col], HEX);
    Serial.print(",");
  }
  Serial.print("\r\n");
  #else
  // Gets rid of the warning for an unused variable.
  (void *)buffer;
  #endif // SERIAL_DEBUG
}

/******************************************************************************
  Sends a quarter row of data to the device.

  @param pEpd
         Pointer to the display object.
  @param buffer
         The buffer for one half line.          
******************************************************************************/
void sendQuarterRow(Epd *pEpd, char *buffer) {
  for(int col = 0; col< EPD_WIDTH /8 ; col++ ) {
    pEpd->SendData(buffer[col]);
  }
}

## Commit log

2024-12-05 add gerber files for atmega328p
    [epaper_board_layout-B_Mask.gbs, epaper_board_layout-B_Paste.gbp, epaper_board_layout-B_Silkscreen.gbo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]
2025-01-04 remove all contents to make room for UNO version
    [epaper_board_layout-B_Mask.gbs, epaper_board_layout-B_Paste.gbp, epaper_board_layout-B_Silkscreen.gbo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]
2025-01-04 add gerber and schematics
    [epaper_board_layout-B_Mask.gbs, epaper_board_layout-B_Paste.gbp, epaper_board_layout-B_Silkscreen.gbo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]
2025-01-07 update to 328p instead of esp32
    [epaper_board_layout-B_Mask.gbs, epaper_board_layout-B_Paste.gbp, epaper_board_layout-B_Silkscreen.gbo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]
2025-01-09 add pcb images
2025-01-21 Add stl and update readme
    [PiInk_stand_7.3_Inch.stl]
2025-03-23 add stl files
2025-03-27 update stls
    [ePaper-7.5-v2-back-no-battery-compartment.3mf, ePaper-7.5-v2-back.3mf, ePaper-7.5-v2-front-chamfer.3mf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]
